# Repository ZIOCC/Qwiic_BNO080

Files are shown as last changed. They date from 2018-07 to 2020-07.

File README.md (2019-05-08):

# Zio Qwiic 9DOF IMU BNO080

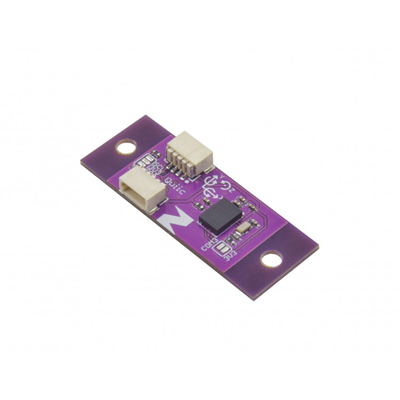
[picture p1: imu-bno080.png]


> This product can be available for purchase [here](https://www.smart-prototyping.com/Zio-9DOF-IMU-BNO080.html).

#### Description

This IC has a combination triple axis accelerometer/gyro/magnetometer packaged with an ARM Cortex M0+ running powerful algorithms. The BNO080 Inertial Measurement Unit (IMU) produces accurate rotation vector headings, excellently suited for VR and other heading applications with a static rotation error of 2 degrees or less. It’s what we’ve been waiting for: all the sensor data is combined and drift corrected into meaningful, accurate IMU information.

> Note: As with all of the Version 1.0 Zio Qwiic boards, this board has been produced with the I2C pull-ups disconnected by default. If there's a significant length of wire between this board and your MCU, you'll need to solder closed the solder jumpers (labeled SDA, 3v3 and SCL) to connect the pull-up resistors to VCC.

#### Specification

* Rotation Vector
  * Dynamic Error: 3.5°
  * Static Error: 2.0°
* Gaming Rotation Vector
  * Dynamic Error: 2.5°
  * Static Error: 1.5°
  * Heading Drift: 0.5° / min
* Geomagnetic Rotation Vector
  * Dynamic Rotation Error: 4.5°
  * Static Rotation Error: 3.0°
* Gravity Angle Error: 1.5°
* Linear Acceleration Accuracy: 0.35m/s2
* Accelerometer Accuracy: 0.3m/s2
* Gyroscope Accuracy: 3.1° / sec
* Magnetometer Accuracy: 1.4µT
* IC: BNO080
* I2C address: 0x4A, 0x4B (Default: 0x4A)
* Dimension: 13.9x 36.2mm(with mounting tab), 13.9x24.7mm(without mounting tab).
* Weight: 1.2g

#### Links

* [Eagle File and Schematic](https://github.com/ZIOCC/Qwiic_BNO080)
* [BNO080 Datasheet](https://www.smart-prototyping.com/image/data/NOA-RnD/101894%209DOF%20IMU%20BNO080/BNO080%20Datasheet%20v1.3.pdf)
* [SparkFun Library](https://github.com/sparkfun/SparkFun_BNO080_Arduino_Library)

> ###### About Zio
> Zio is a new line of open sourced, compact, and grid layout boards, fully integrated for Arduino and Qwiic ecosystem. Designed ideally for wearables, robotics, small-space limitations or other on the go projects. Check out other awesome Zio products [here](https://www.smart-prototyping.com/Zio).

> All Zio products are released under the [Creative Commons Attribution, Share-Alike License](https://creativecommons.org/licenses/by-sa/4.0/), and in accordance with the principles of the [Open Source Hardware Association's OSHW Statement of Principles 1.0 and OSHW Definition 1.0](https://www.oshwa.org/definition/).

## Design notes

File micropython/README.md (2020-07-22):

This is a demo code for the BNO055 sensor module, the testing is based on pyboard, the Qwiic BNO055 and the Qwiic 0.91OLED display module. Just copy and paste the code to pyboard, then you are good to go!
Connection: 
Use the Qwiic cable plug the 0.91 OLED display to the I2C 1 port, and connect the BNO055 to the I2C 2 port. 
You are free to change the I2C port, but you need to config the right settings for the I2C. The OLED display needs a soft I2C initiation to work. Use I2C(sda=Pin("pinname"),scl=Pin("pinname")). 
The BNO055 driver is based on Adafruit's micropython BNO055 library.

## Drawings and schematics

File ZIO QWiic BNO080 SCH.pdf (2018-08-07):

1 | 2 | 3 | 4 | 5 | 6

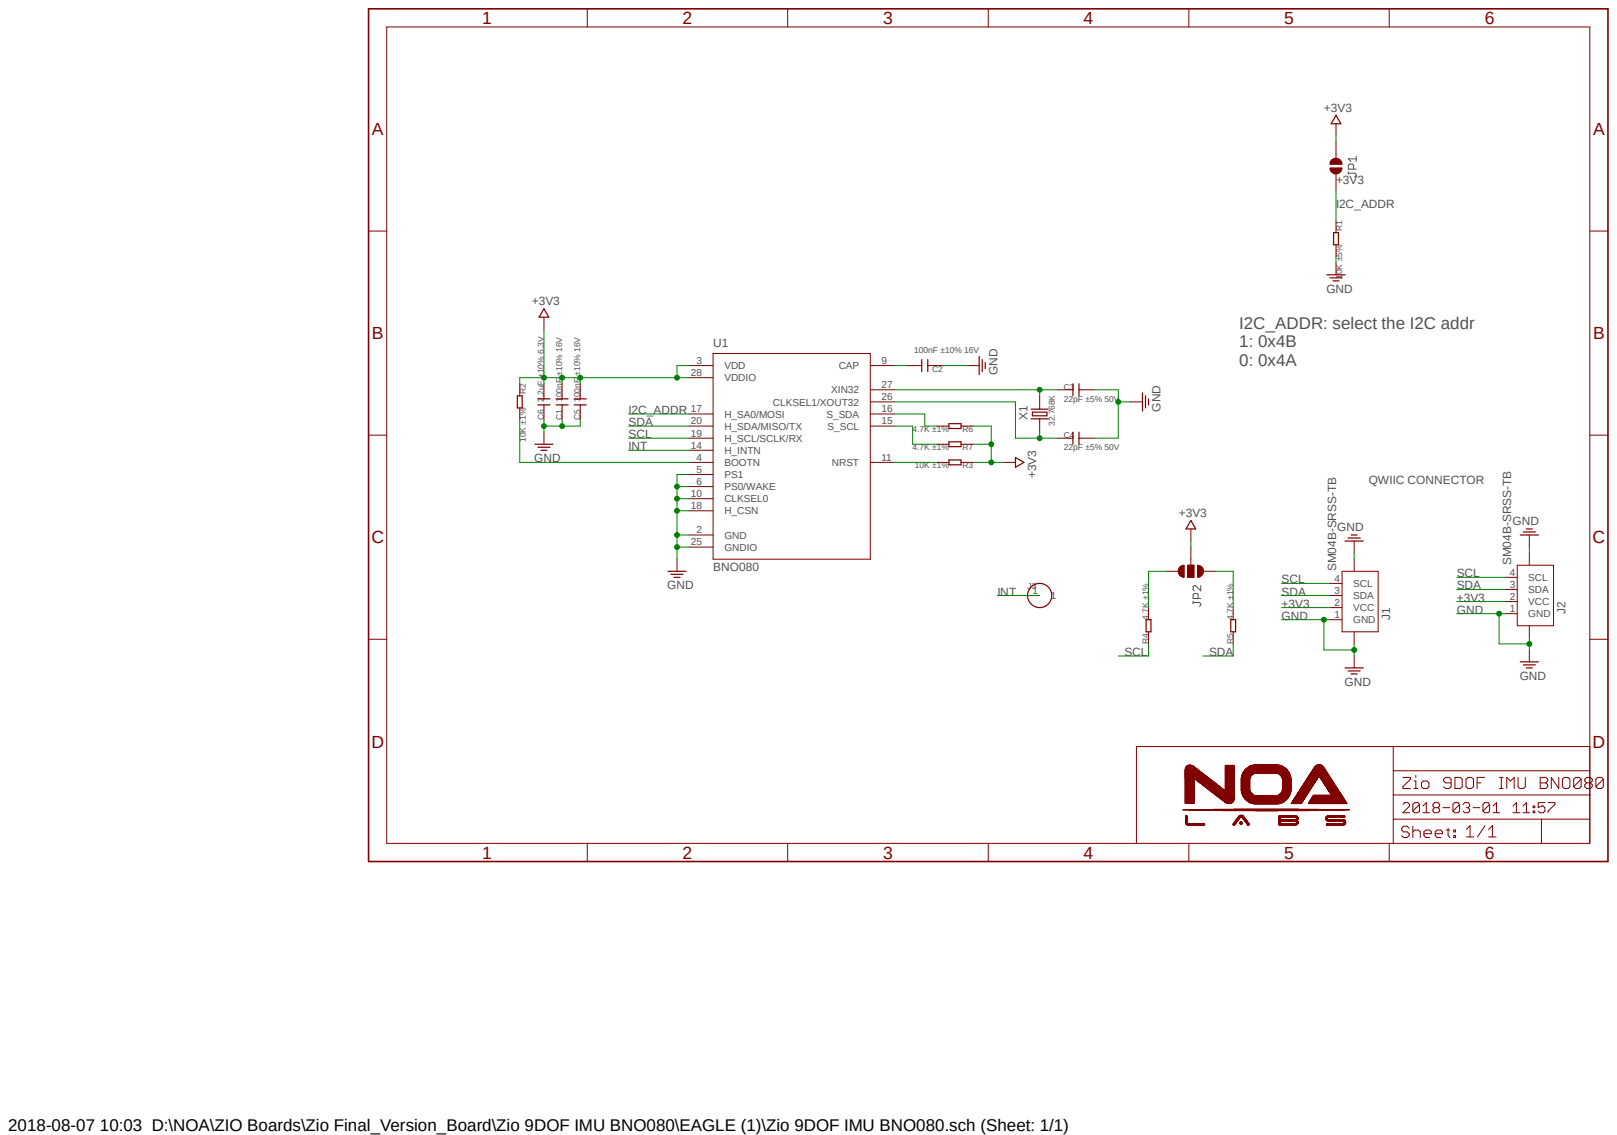
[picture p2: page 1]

+3V3 100nF ±10% ¹⁶V

2018-08-07 10:03 D:\NOA\ZIO Boards\Zio Final_Version_Board\Zio 9DOF IMU BNO080\EAGLE (1)\Zio 9DOF IMU BNO080.sch (Sheet: 1/1)

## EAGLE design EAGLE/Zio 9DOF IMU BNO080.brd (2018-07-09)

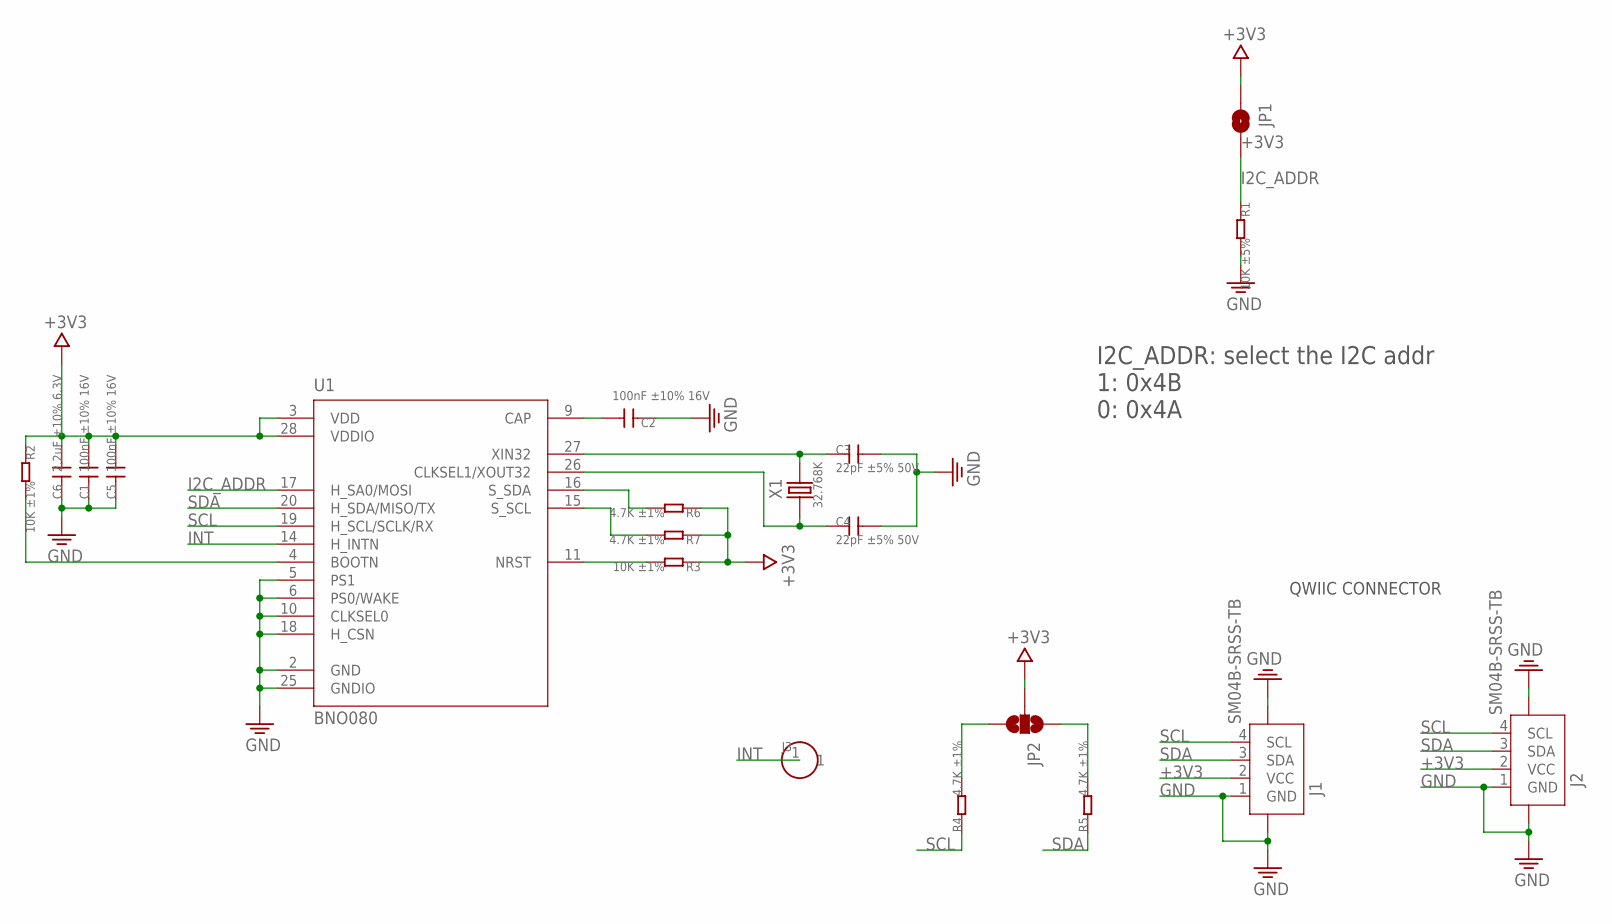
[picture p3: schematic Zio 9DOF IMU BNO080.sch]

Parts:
C1, C2, C5: 100nF ±10% 16V; 0402
C3, C4: 22pF ±5% 50V; 0402
C6: 2.2uF ±10% 6.3V; 0402
J1, J2: SM04B-SRSS-TB; JST-SH-4P
J3: HEADER-1P-40MIL; 1P-40MIL-AUTO
JP1: JUMPER-SMT_2_NO_SILK; SMT-JUMPER_2_NO_SILK
JP2: JUMPER-SMT_3_2-NC_PASTE_NOCREM; SMT-JUMPER_3_2-NC_PASTE_SILK_NOCREM
R1: 10K ±5%; 0402
R2, R3: 10K ±1%; 0402
R4, R5, R6, R7: 4.7K ±1%; 0402
U1: BNO080; IC_LGA-28_3.80X5.20/0.5
X1: 32.768K; 2.0X12MM

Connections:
+3V3: C1.2, C5.2, C6.2, J1.2 (VCC), J2.2 (VCC), JP1.1, JP2.2, R2.1, R3.1, R6.1, R7.1, U1.3 (VDD), U1.28 (VDDIO)
GND: C1.1, C2.1, C3.2, C4.2, C5.1, C6.1, J1.1 (GND), J1.NC1 (5), J1.NC2 (6), J2.1 (GND), J2.NC1 (5), J2.NC2 (6), R1.2, U1.2 (GND), U1.5 (PS1), U1.6 (PS0/WAKE), U1.10 (CLKSEL0), U1.18 (H_CSN), U1.25 (GNDIO)
I2C_ADDR: JP1.2, R1.1, U1.17 (H_SA0/MOSI)
INT: J3.1, U1.14 (H_INTN)
unnamed: C2.2, U1.9 (CAP)
unnamed: R3.2, U1.11 (NRST)
unnamed: R6.2, U1.16 (S_SDA)
unnamed: C3.1, U1.27 (XIN32), X1.2
unnamed: C4.1, U1.26 (CLKSEL1/XOUT32), X1.1
unnamed: R2.2, U1.4 (BOOTN)
unnamed: R7.2, U1.15 (S_SCL)
unnamed: JP2.3, R4.2
unnamed: JP2.1, R5.2
SCL: J1.4 (SCL), J2.4 (SCL), R4.1, U1.19 (H_SCL/SCLK/RX)
SDA: J1.3 (SDA), J2.3 (SDA), R5.1, U1.20 (H_SDA/MISO/TX)

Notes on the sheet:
I2C_ADDR: select the I2C addr 1: 0x4B 0: 0x4A
QWIIC CONNECTOR

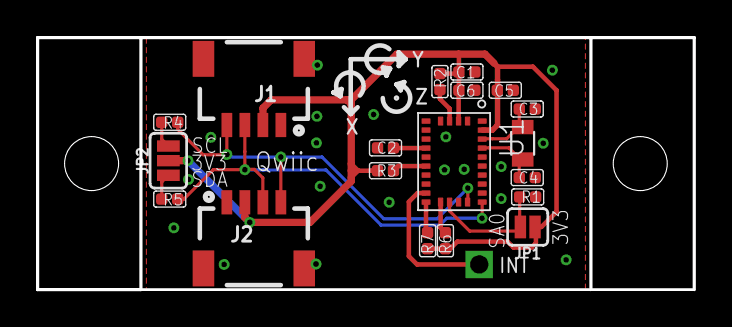
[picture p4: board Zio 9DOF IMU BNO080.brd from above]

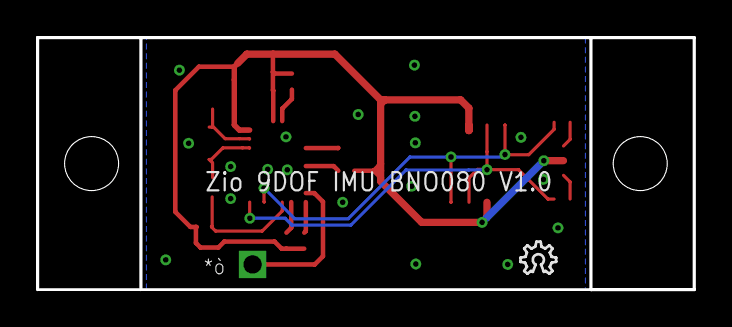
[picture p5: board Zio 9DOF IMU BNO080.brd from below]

Board: 2 copper layers, 36.5 x 14.0 mm, 23 parts (2 on the bottom side), 15 nets.

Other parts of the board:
E$3: 6MM
LOGO2: LOGO-OSHW-6MILX0070-NT; OSHW_6X70_NOTEXT
U$6: 6MM

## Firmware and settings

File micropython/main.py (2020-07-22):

from machine import Pin, I2C
import time
from bno055 import *
from ssd1306 import SSD1306_I2C

i2c1 = I2C(sda=Pin("X10"), scl=Pin("X9"))
oled = SSD1306_I2C(128, 32, i2c1, addr=0x3c)

i2c2 = I2C(2)
imu = BNO055(i2c2)
calibrated = False


while True:
    time.sleep_ms(10)
    if not calibrated:
        calibrated = imu.calibrated()
        print('Calibration required: sys {} gyro {} accel {} mag {}'.format(*imu.cal_status()))
    print('Temperature {}°C'.format(imu.temperature()))
    print('Mag       x {:5.0f}    y {:5.0f}     z {:5.0f}'.format(*imu.mag()))
    print('Gyro      x {:5.0f}    y {:5.0f}     z {:5.0f}'.format(*imu.gyro()))
    print('Accel     x {:5.1f}    y {:5.1f}     z {:5.1f}'.format(*imu.accel()))
    print('Lin acc.  x {:5.1f}    y {:5.1f}     z {:5.1f}'.format(*imu.lin_acc()))
    print('Gravity   x {:5.1f}    y {:5.1f}     z {:5.1f}'.format(*imu.gravity()))
    print('Heading     {:4.0f} roll {:4.0f} pitch {:4.0f}'.format(*imu.euler()))
    oled.fill(0)
    oled.text('Accel x: ' + str(imu.accel()[0]), 0, 0)
    oled.text('Accel y: ' + str(imu.accel()[1]), 0, 10)
    oled.text('Accel z: ' + str(imu.accel()[2]), 0, 20)
    oled.show()
    pyb.delay(300)

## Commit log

2018-07-09 Eagle PCB schematic and layout initial upload
    [Zio 9DOF IMU BNO080.brd, Zio 9DOF IMU BNO080.sch]
2018-08-07 Add files via upload
    PDF version of ZIO Qwiic BNO080 schematic

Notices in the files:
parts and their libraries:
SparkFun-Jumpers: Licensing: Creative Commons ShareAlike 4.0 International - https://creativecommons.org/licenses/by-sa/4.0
